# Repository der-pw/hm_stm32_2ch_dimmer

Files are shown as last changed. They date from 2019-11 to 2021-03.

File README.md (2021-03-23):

# hm_stm32_2ch_dimmer

Platinendesign für einen Asksin++ 2 Kanaldimmer, der mit einem STM32 angetrieben wird.
Basiert auf der guten Vorarbeit von pa-pa und seinem STM32 Dimmer https://github.com/pa-pa/STM32Dimmer

top
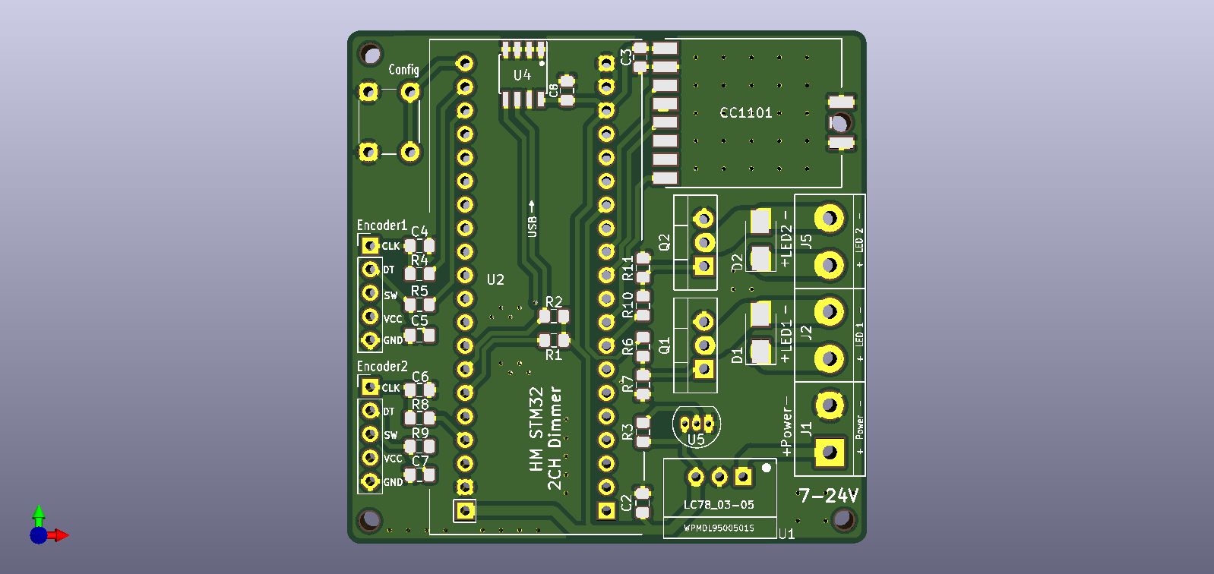
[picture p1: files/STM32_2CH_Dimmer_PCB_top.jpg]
top


bottom
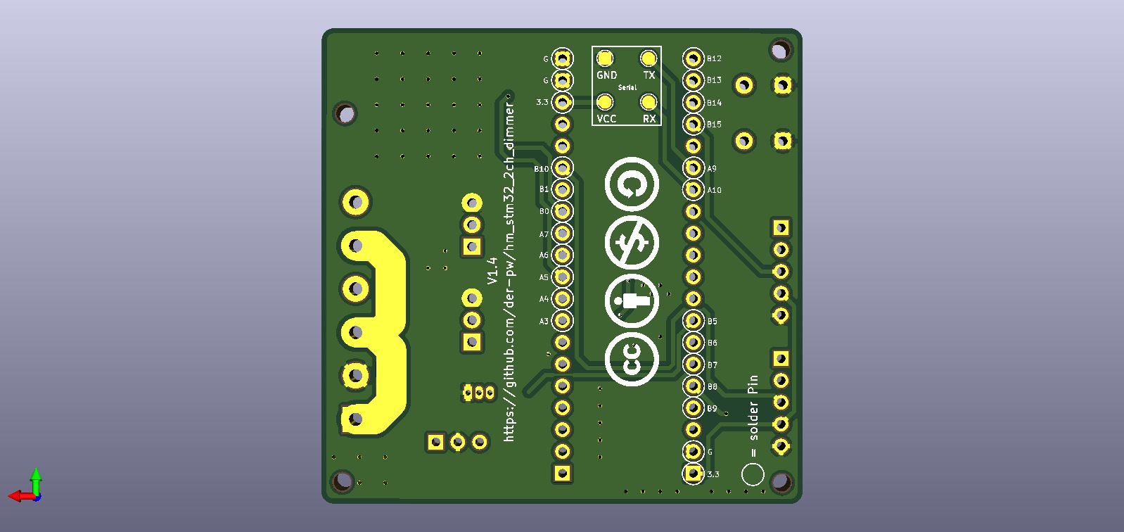
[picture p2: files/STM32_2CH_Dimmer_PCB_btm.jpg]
bottom bottm


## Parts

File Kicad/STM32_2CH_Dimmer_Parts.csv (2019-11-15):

Reference | Quantity | Value | Footprint | Datasheet
C2 | 1 | 22µ | Capacitor_SMD:C_0805_2012Metric_Pad1.15x1.40mm_HandSolder
C3 C8 C7 C6 C5 C4 | 6 | 100n | Capacitor_SMD:C_0805_2012Metric_Pad1.15x1.40mm_HandSolder
D1 D2 | 2 | SS14 | Diodes_SMD:D_SMA | https://de.aliexpress.com/item/100PCS-SMA-Rectifier-diode-1N5819-SS14-1N5822-SS34-SR160-SS16-1N5817-SS12-SR1100-SS110-SR360-SS36/32849859393.html
J1 | 1 | Power | Terminal_Blocks:TerminalBlock_bornier-2_P5.08mm | ~
J2 | 1 | LED1 | Terminal_Blocks:TerminalBlock_bornier-2_P5.08mm | ~
J3 | 1 | Encoder1 | Pin_Headers:Pin_Header_Straight_1x05_Pitch2.54mm | ~
J4 | 1 | Encoder2 | Pin_Headers:Pin_Header_Straight_1x05_Pitch2.54mm | ~
J5 | 1 | LED2 | Terminal_Blocks:TerminalBlock_bornier-2_P5.08mm | ~
Q1 Q2 | 2 | IRF3708 | Package_TO_SOT_THT:TO-220-3_Vertical
R1 R2 R3 | 3 | 4k7 | Resistor_SMD:R_0805_2012Metric_Pad1.15x1.40mm_HandSolder
R6 R10 | 2 | 100R | Resistor_SMD:R_0805_2012Metric_Pad1.15x1.40mm_HandSolder
R7 R11 | 2 | 100k | Resistor_SMD:R_0805_2012Metric_Pad1.15x1.40mm_HandSolder
R8 R9 R4 R5 | 4 | 10k | Resistor_SMD:R_0805_2012Metric_Pad1.15x1.40mm_HandSolder
SW1 | 1 | Config | Button_Switch_THT:SW_PUSH_6mm_H4.3mm | https://de.aliexpress.com/item/100PCS-LOT-3-4-2MM-Micro-button-3X4X2-tact-switch-2-pin-little-turtle-single-shrapnel/32698846968.html
TP1 TP2 TP3 TP4 | 4 | TestPoint | TestPoint:TestPoint_Pad_D1.5mm | ~
U1 | 1 | LC78_03-05 | Homebrew:LC78_03-05 | https://www.reichelt.de/dc-dc-wandler-1-65-w-3-3-v-500-ma-to-220-lc78-03-0-5-p242822.html
U2 | 1 | STM32F103Generic | Homebrew:STM32F103Generic | https://de.aliexpress.com/item/STM32F103CBT6-Maple-Mini-ARM-STM32-Cortex-M3-Controller-Board-Module-3-3V-USB-Digital-IO-PWM/32292673542.html
U3 | 1 | CC1101 | Homebrew:CC1101_Module | https://de.aliexpress.com/item/CC1101-Wireless-Module-Long-Distance-Transmission-Antenna-868MHZ-M115-Free-Shipping/32803645858.html
U4 | 1 | AT24CS32 | Housings_SOIC:SOIC-8_3.9x4.9mm_Pitch1.27mm | https://de.aliexpress.com/item/20PCS-24c32-AT24c32-SOP8-AT24C32AN-10SU-2-7-make-in-china/1517186522.html
U5 | 1 | DS18B20 | TO_SOT_Packages_THT:TO-92_Inline_Narrow_Oval | https://de.aliexpress.com/item/DS18B20-18B20-Programmable-Resolution-1-Wire-Digital-Thermometer-IC-TO-92/32794981963.html

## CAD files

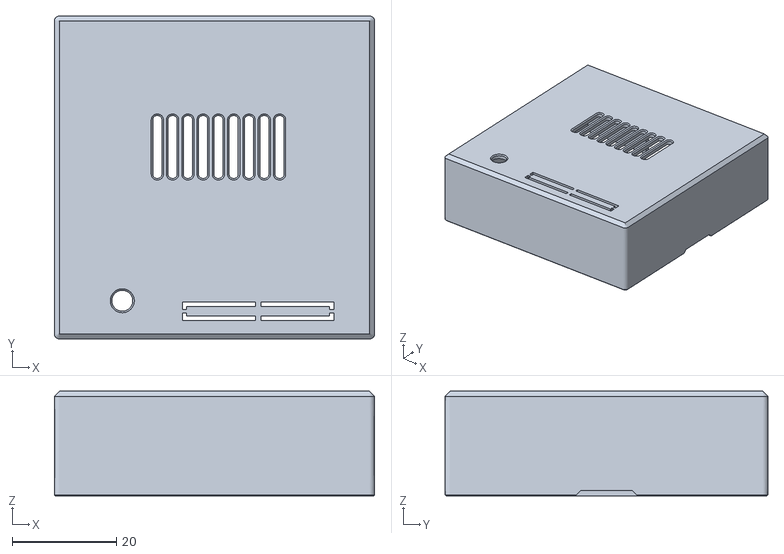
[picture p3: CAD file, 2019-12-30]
Gehaeuse/Deckel.stl
61.4 x 61.9 x 20.1

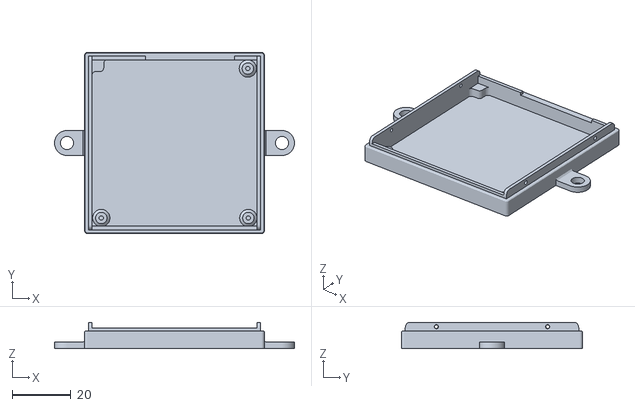
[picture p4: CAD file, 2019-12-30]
Gehaeuse/Grundplatte.stl
81.9 x 61.9 x 9.00

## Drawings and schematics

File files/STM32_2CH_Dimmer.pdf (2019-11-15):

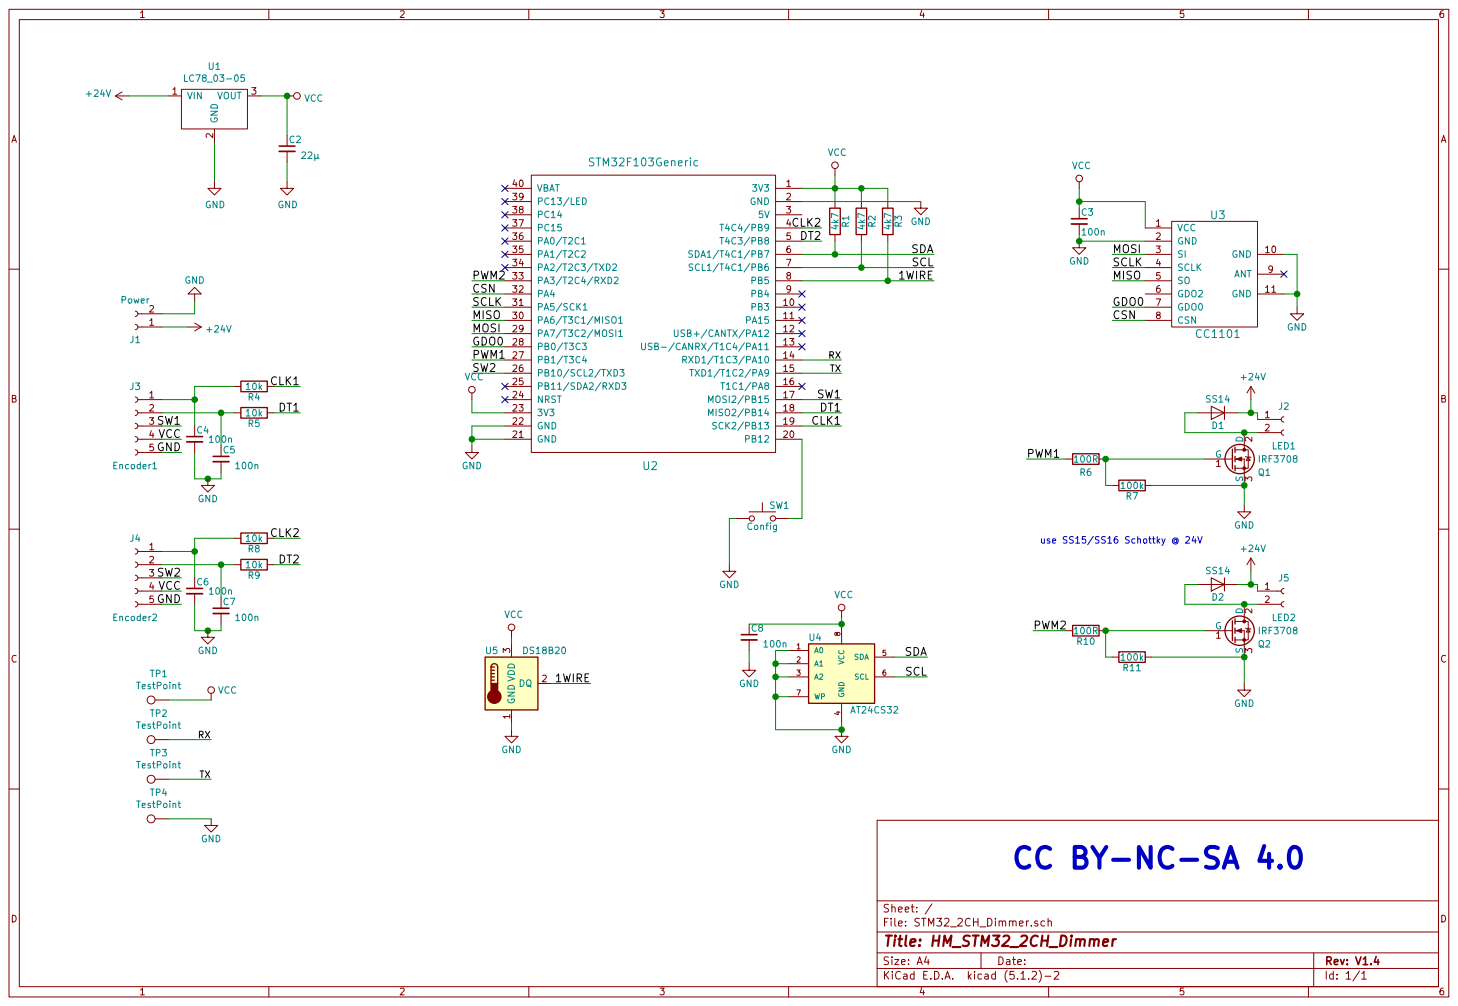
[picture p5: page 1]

4 SDA 5 SCL 6 WP 7 VCC

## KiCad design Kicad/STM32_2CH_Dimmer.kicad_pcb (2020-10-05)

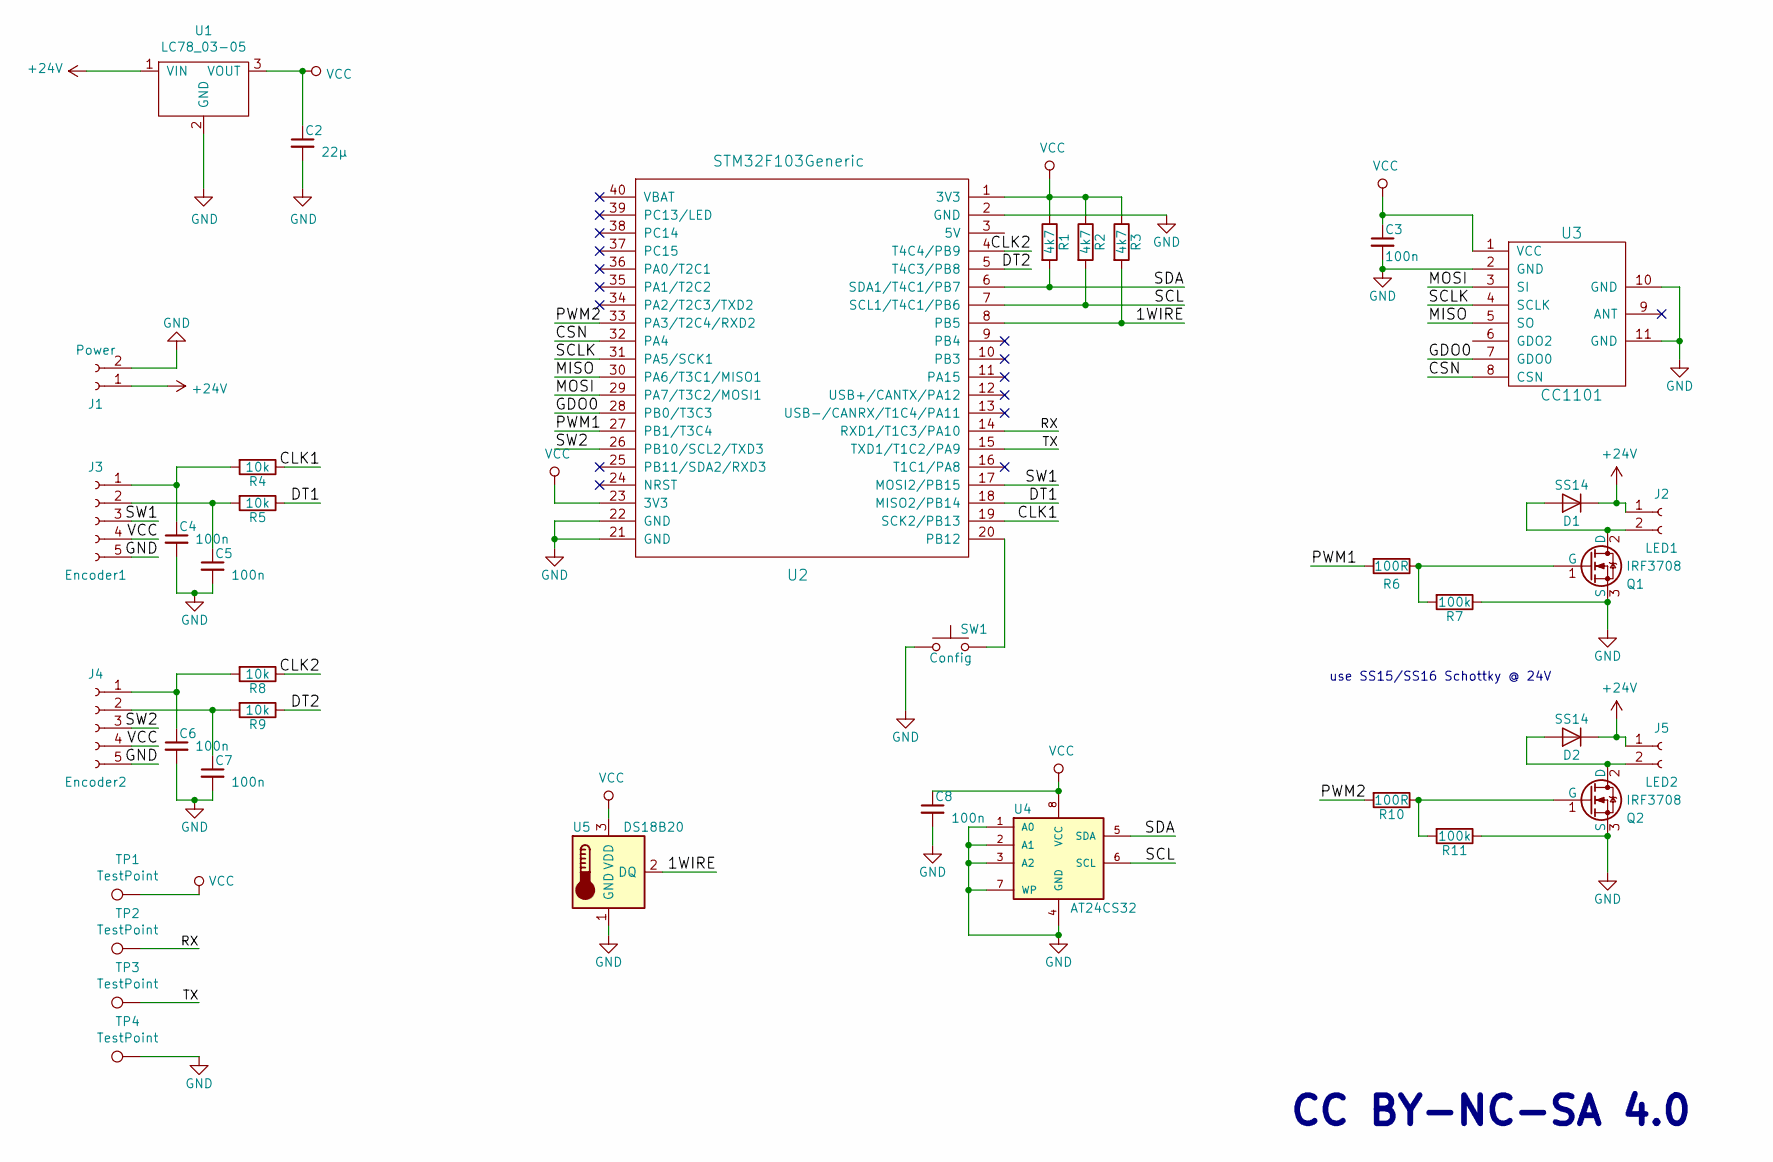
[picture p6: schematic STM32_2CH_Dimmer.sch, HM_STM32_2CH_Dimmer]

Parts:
C2: 22µ; C_0805_2012Metric_Pad1.15x1.40mm_HandSolder
C3, C4, C5, C6, C7, C8: 100n; C_0805_2012Metric_Pad1.15x1.40mm_HandSolder
D1, D2: SS14; D_SMA
J1: Power; TerminalBlock_bornier-2_P5.08mm
J2: LED1; TerminalBlock_bornier-2_P5.08mm
J3: Encoder1; Pin_Header_Straight_1x05_Pitch2.54mm
J4: Encoder2; Pin_Header_Straight_1x05_Pitch2.54mm
J5: LED2; TerminalBlock_bornier-2_P5.08mm
Q1, Q2: IRF3708; TO-220-3_Vertical
R1, R2, R3: 4k7; R_0805_2012Metric_Pad1.15x1.40mm_HandSolder
R4, R5, R8, R9: 10k; R_0805_2012Metric_Pad1.15x1.40mm_HandSolder
R6, R10: 100R; R_0805_2012Metric_Pad1.15x1.40mm_HandSolder
R7, R11: 100k; R_0805_2012Metric_Pad1.15x1.40mm_HandSolder
SW1: Config; SW_PUSH_6mm_H4.3mm
TP1, TP2, TP3, TP4: TestPoint; TestPoint_Pad_D1.5mm
U1: LC78_03-05
U2: STM32F103Generic
U3: CC1101; CC1101_Module
U4: AT24CS32; SOIC-8_3.9x4.9mm_Pitch1.27mm
U5: DS18B20; TO-92_Inline_Narrow_Oval

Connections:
+24V: D1.1 (K), D2.1 (K), J1.1, J2.1, J5.1, U1.1 (VIN)
/1WIRE: R3.2, U2.8 (PB5), U5.2 (DQ)
/CLK1: R4.1, U2.19 (SCK2/PB13)
/CLK2: R8.1, U2.4 (T4C4/PB9)
/CSN: U2.32 (PA4), U3.8 (CSN)
/DT1: R5.1, U2.18 (MISO2/PB14)
/DT2: R9.1, U2.5 (T4C3/PB8)
/GDO0: U2.28 (PB0/T3C3), U3.7 (GDO0)
/MISO: U2.30 (PA6/T3C1/MISO1), U3.5 (SO)
/MOSI: U2.29 (PA7/T3C2/MOSI1), U3.3 (SI)
/PWM1: R6.2, U2.27 (PB1/T3C4)
/PWM2: R10.2, U2.33 (PA3/T2C4/RXD2)
/RX: TP2.1, U2.14 (RXD1/T1C3/PA10)
/SCL: R2.2, U2.7 (SCL1/T4C1/PB6), U4.6 (SCL)
/SCLK: U2.31 (PA5/SCK1), U3.4 (SCLK)
/SDA: R1.2, U2.6 (SDA1/T4C1/PB7), U4.5 (SDA)
/SW1: J3.3, U2.17 (MOSI2/PB15)
/SW2: J4.3, U2.26 (PB10/SCL2/TXD3)
/TX: TP3.1, U2.15 (TXD1/T1C2/PA9)
GND: C2.2, C3.2, C4.2, C5.2, C6.2, C7.2, C8.2, J1.2, J3.5, J4.5, Q1.3 (S), Q2.3 (S), R7.1, R11.1, SW1.1, TP4.1, U1.2 (GND), U2.2 (GND), U2.21 (GND), U2.22 (GND), U3.2 (GND), U3.10 (GND), U3.11 (GND), U4.1 (A0), U4.2 (A1), U4.3 (A2), U4.4 (GND), U4.7 (WP), U5.1 (GND)
unnamed: C4.1, J3.1, R4.2
unnamed: C5.1, J3.2, R5.2
unnamed: C6.1, J4.1, R8.2
unnamed: C7.1, J4.2, R9.2
unnamed: D1.2 (A), J2.2, Q1.2 (D)
unnamed: D2.2 (A), J5.2, Q2.2 (D)
unnamed: Q1.1 (G), R6.1, R7.2
unnamed: Q2.1 (G), R10.1, R11.2
unnamed: SW1.2, U2.20 (PB12)
VCC: C2.1, C3.1, C8.1, J3.4, J4.4, R1.1, R2.1, R3.1, TP1.1, U1.3 (VOUT), U2.1 (3V3), U2.23 (3V3), U3.1 (VCC), U4.8 (VCC), U5.3 (VDD)

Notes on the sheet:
CC BY-NC-SA 4.0
use SS15/SS16 Schottky @ 24V

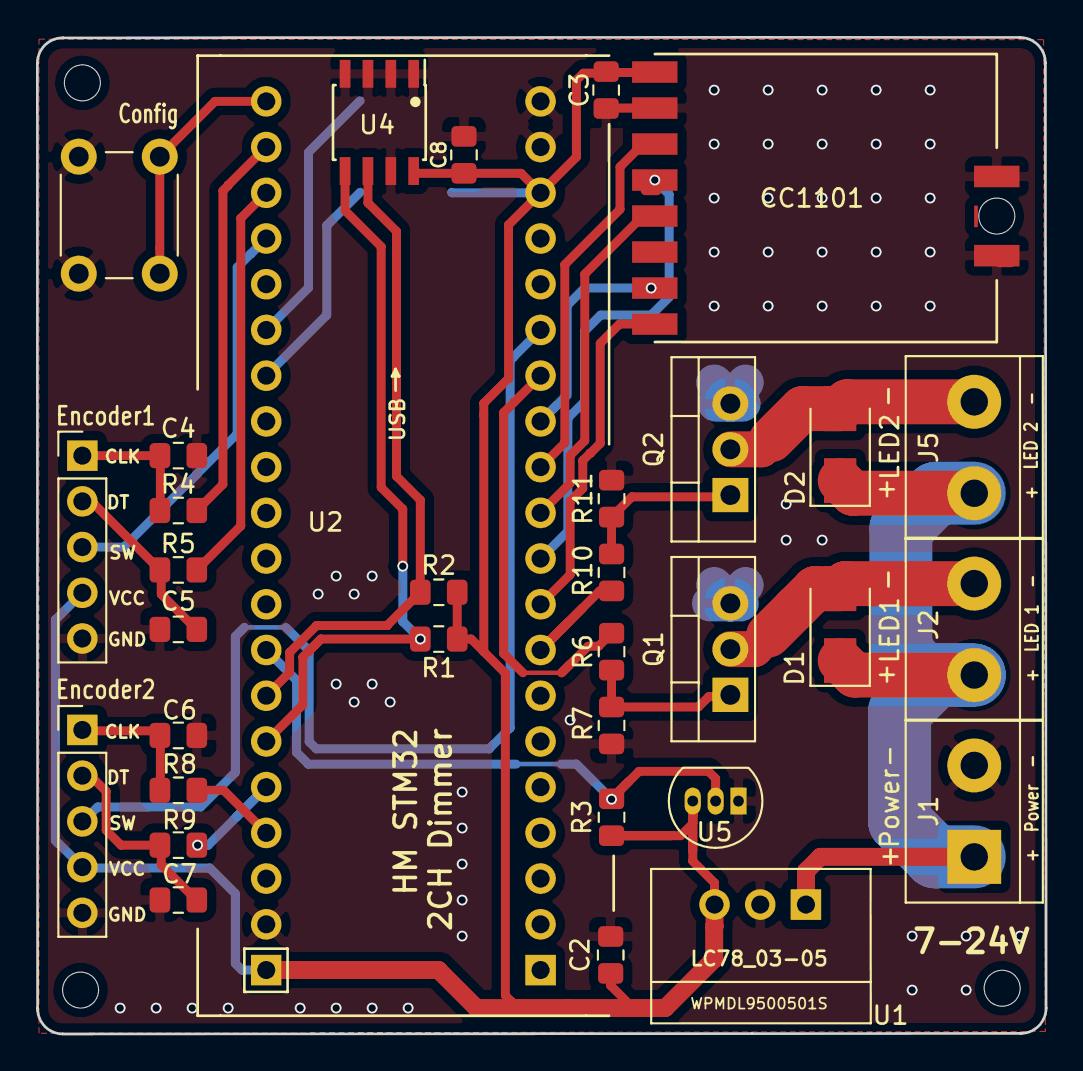
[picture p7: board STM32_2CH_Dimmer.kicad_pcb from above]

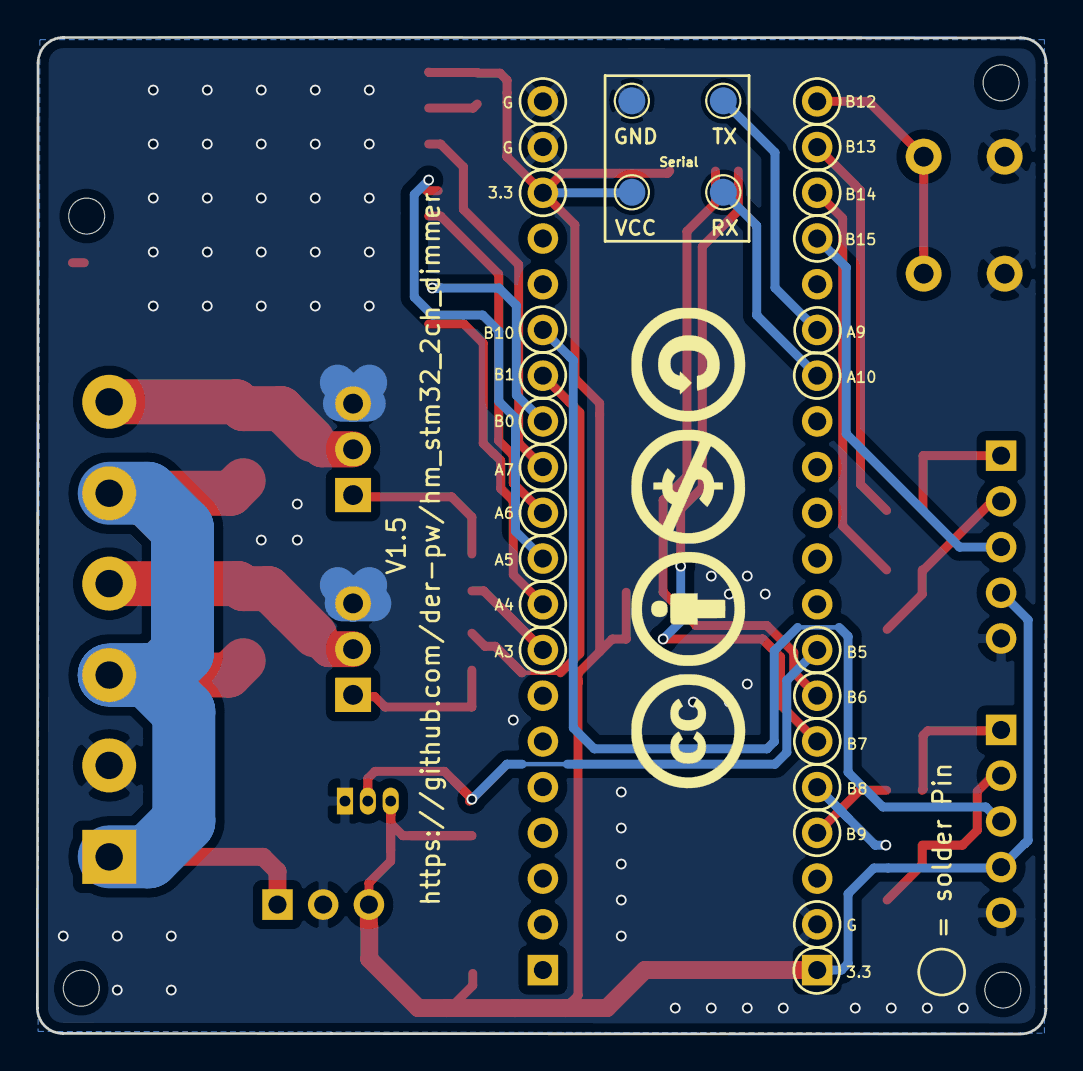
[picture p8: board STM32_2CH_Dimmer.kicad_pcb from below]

Board: 2 copper layers, 56.0 x 55.4 mm, 37 parts (4 on the bottom side), 30 nets.

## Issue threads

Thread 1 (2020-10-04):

Temperatursensor DS18b20 und Platine kaufen oder fertigen lassen?

Triton-KS, 2020-10-04:
Hallo,
ich bin gerade auf der Suche nache einem weiteren LED Dimmer.
Dabei bin ich auf die Seite oder das Projekt aufmerksam geworden.

Wofür wird oder ist der Temperatursensor DS18b20 auf der Platine?

Wo oder wie kann man die Platine kaufen oder darf man die sich "nachbestellen" z.B. bei jlcpcb
und funktioniert das mit den Patinen-Dateien da?

der-pw, 2020-10-05:
Hallo,

der DS18b20 überwacht die Temperatur im Gehäuse, sofern die Platine in
einem Gehäuse verbaut ist.
In der CCU kann eingestellt werden, bei welcher Temperatur um wieviel
Prozent abgedimmt werden soll, wenn es doch mal zu heiß wird, einfach um
Last wegzunehmen.
Ist mir bislang aber noch nicht passiert.

Selbstverständlich kannst du dir die Platinen bei JLC nachbestellen.
Einfach den Ordner "gerber" als Zip-File dort hochladen.
Von der V1.5 hab ich leider keine da.
Eben habe ich das Repo nochmal aufgeräumt, dort findest du jetzt auch eine
gerber.zip. Die kannst du jetzt einfach bei JLC hochladen.

Schöne Grüße,
Patrick

Am So., 4. Okt. 2020 um 22:32 Uhr schrieb Triton-KS <
notifications@github.com>:

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

Triton-KS, 2020-10-05:
Hallo Patrick,

Danke für deine schnelle Rückmeldung.
Mit dem DS18b20 habe ich mir schon sowas gedacht. Kann man den DS18B20 auch als "normalen" Temperatursensor
in / mit der CCU verwenden?

Den Gerber-Ordner als Zip erstellen, ist mir dann auch wieder eingefallen. Hatte bisher nur einmal Platinen bestellt.
So ok dann muss ich nur noch schauen ob der AT24CS32 typengleich mit dem vom Reichelt ist:
[https://www.reichelt.de/eeprom-32-kb-4096-x-8-25-5-5-v-so-8-st-24c32-mn6-p33376.html?&trstct=pos_0&nbc=1](url)
benötigt man hier ggf 64 kB oder bring ein Wechsel eher Probleme ?

Letzte Frage gibt es Unterschiede zwischen STM32F103C**B**T6 und STM32F103C**8**T6 oder wenn man den STM32F103C**B**T6 nicht bekommt gibt es eine Alternative?

Schöne Grüße

Triton-KS / Alex

Closed 2020-10-14.

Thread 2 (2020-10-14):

STM32F103 Bild und Bestelllink unterschiedlich

Triton-KS, 2020-10-14:
Hallo,
ich bin noch etwas verunsichert über den STM32F103
Es scheint ja ein Maple Mini zu sein oder ist es ein Blue Pill?
Leider ist der STM32F103 über den Bestelllink optisch ein völlig anderer
Artikel. Gibt es hier Hilfestellungen auf was man achten muss?

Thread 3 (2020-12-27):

Memory/EEPROM 64kB oder nur 32kB

Triton-KS, 2020-12-27:
Hi,
ist es auch möglich einen EEPROM mit 64kB zu benutzen?
Auf was sollte man hierbei achten?

Danke

der-pw, 2020-12-28:
Hallo,
kann ich gar nicht genau beantworten.
Wobei 64kB wohl etwas groß sein dürfte, ob aber auch 64k**b** gehen weiß ich nicht. ;-)

Wenn es dir aber nur darum geht, dass der AT24C**S**32 schlecht verfügbar ist, der AT24C32 geht auch.
https://homematic-forum.de/forum/viewtopic.php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

Triton-KS, 2020-12-28:
Hallo,
Dankeschön.
Genau den im Forum beschriebenen oder als Link bei Reichelt benannten habe ich bestellt.
Leider muss ich hier nochmal genauer schauen oder herausfinden wo der Pin 1 ist. Es fehlen auf den bestellten EEPROMs der Markierungspunkt. Aber sollte man ja herausfinden.
Gestatten Sie oder du mir noch die Frage was die Aufgabe vom EEPROM genau ist? Einfach nur um es zu verstehen.
Danke

der-pw, 2020-12-28:
"du" ist vollkommen in Ordnung.

Im EEPROM werden die Deviceparamter und Peerings gespeichert.
Quasi das was du in der CCU für das jeweilige Gerät konfigurieren kannst.
(achtung gefährliches Halbwissen) Der STM32 besitzt kein internes EEPROM wie bspw. der AT328P, sondern nur Flashspeicher, welcher IMHO weniger Schreibzyklen als eben ein EEPROM verträgt.

Ja, die sind ja witzig bei ST. :-D
Hab mir meine, bei Reichelt bestellten noch nie angeguckt, da ich noch von ein paar AT-Chips zehre, und so oft baue ich den Dimmer jetzt nicht zusammen.

Wenn sich die Ausrichtung des Aufdrucks analog zum Atmel-EEPROM verhält, sollte Pin1 unten links sein.
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

Triton-KS, 2020-12-29:
Servus,
scheinbar lernt man noch mehr durch das Bauen.
ST machen die Kennzeichnung wohl über die Form.
Erkennt man ja auh gut über die Vergrößerung

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

der-pw, 2020-12-29:
Ah, sehr gut!
Haben wir wieder was gelernt.

Danke für die Info.

Closed 2020-12-29.

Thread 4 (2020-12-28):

Encoder1/2 Funktion?

Triton-KS, 2020-12-28:
Hallo,
die Encoder 1 und Encoder 2 dienen zur externen "Ansteuerung / Helligkeitsveränderung" der angeschlossenen LEDs,
ist das richtig?
Und wenn ja wie steuert man diese dann genau an oder gibt es dafür auch einen Schaltung oder Platine?

der-pw, 2020-12-28:
Im Prinzip brauchst du nichts weiter als einen Drehencoder.
https://www.amazon.de/RoboMall-Drehencoder-Drehgeber-KY-040-Modul/dp/B00QHEMUQK

Den verbindest du gemäß der Pinbezeichnung auf der Platine, und das Hühnerfutter natürlich nicht vergessen.
In den meisten Sketches sollte das dank pa-pa auch eingebaut sein.
https://github.com/pa-pa/AskSinPP/blob/master/examples/stm32/HM-LC-DW-WM/HM-LC-DW-WM.ino#L74-L75

Triton-KS, 2020-12-28:
Ohje danke,
was man nicht alles nach ca. 20 Jahren Lehre an Begriffen vergisst oder einfach zu kompliziert Denkt.
Keine Ahnung was ist hier für eine "wilde" Schaltung erwartet hatte. Aber naja wenn man erst wieder anfängt zu "Basteln" oder sind nebenbei mit Platinen zu beschäftigen, hat man halt noch Wissenslücken.

Dankeschön

Closed 2020-12-29.

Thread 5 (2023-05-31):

Teileliste down

DennisXK, 2023-05-31:
Hi kannst du die Teileliste neu hochladen, denn die ist down!

der-pw, 2023-06-01:
https://github.com/der-pw/hm_stm32_2ch_dimmer/blob/master/Kicad/STM32_2CH_Dimmer_Parts.csv
was ist denn mit dieser Liste hier?

DennisXK, 2023-06-01:
Ok danke. Hätte noch ein paar Fragen...

-kann man für den EPROM auch einen anderen benutzen? Denn den gibt es beim Conrad, RS, Reichelt nicht. Hättest du du ein alternative EMPROM?

-Der DS18B20 wird der auch ausgelesen und von der Homematic Oberfläche angezeigt? Wäre cool wenn das so wäre :D

-J2 und J3: benötigt man für was genau? Denke nicht das die für den Dimmer nötwenig sind

-U2 welchen Controller genau? STM32 F103C6T6 oder STM32 F103C8T6?

Closed 2023-06-12.

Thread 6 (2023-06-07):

Fragen

DennisXK, 2023-06-07:
Habe leider keine Antwort erhalten, deswegen eine neues Issues.

-kann man für den EPROM auch einen anderen benutzen? Denn den gibt es beim Conrad, RS, Reichelt nicht. Hättest du du ein alternative EMPROM?

-Der DS18B20 wird der auch ausgelesen und von der Homematic Oberfläche angezeigt? Wäre cool wenn das so wäre :D

-J2 und J3: benötigt man für was genau? Denke nicht das die für den Dimmer nötwenig sind

-U2 welchen Controller genau? STM32 F103C6T6 oder STM32 F103C8T6?

der-pw, 2023-06-10:
> kann man für den EPROM auch einen anderen benutzen? Denn den gibt es beim Conrad, RS, Reichelt nicht. Hättest du du ein alternative EMPROM?

diesen von ST solltest du nehmen können
https://www.reichelt.de/eeprom-32-kb-4k-x-8-i2c-400-khz-2-5--5-5-v-so-8-st-24c32-mn6-p33376.html

> -Der DS18B20 wird der auch ausgelesen und von der Homematic Oberfläche angezeigt?

nein, er ist nur für die interne Schutzabschaltung

> -J2 und J3: benötigt man für was genau? Denke nicht das die für den Dimmer nötwenig sind

J2 ist der Terminalanschluss für LED1, musst du wissen, wie du deine LED-Strip da verbindest
und J3 der Pinheader um einen Encoder anzuschließen.
Schätze mal, du meist J3 und J4. Die müssen nicht zwingend verwendet werden.

> U2 welchen Controller genau? STM32 F103C6T6 oder STM32 F103C8T6?

Der Blue Pill hat einen STM32F103C8T6 drauf

Closed 2023-06-12.

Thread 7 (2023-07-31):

endcoder ohne Funktion

DennisXK, 2023-07-31:
Hi, ich habe den HM-LC-Dim1PWM-CV aufgespielt. aber leider ist der Drehendcoder ohne funktion. Muss im Sketch noch etwas aktviert werden?

Diese habe ich verwendet. Habe zum Test auch einen zweiten getestet.

https://www.amazon.de/GIAK-Drehwinkelgeber-Druckknopf-Automobilelektronik-Multimedia-Audio/dp/B09726Y8RB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

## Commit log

2019-09-29 some fixes
    [STM32_2CH_Dimmer.kicad_pcb]
2019-11-04 Gerber export
    [STM32_2CH_Dimmer-B_Cu.gbl, STM32_2CH_Dimmer-B_Mask.gbs, STM32_2CH_Dimmer-B_Paste.gbp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]
2019-11-04 part csv
    [STM32_2CH_Dimmer_Parts.csv]
2019-11-08 V1.3
    minor fixes
    add test pads for serial connection
    [STM32_2CH_Dimmer-B_Cu.gbl, STM32_2CH_Dimmer-B_Mask.gbs, STM32_2CH_Dimmer-B_Paste.gbp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]
2019-11-09 info C1
    [STM32_2CH_Dimmer.sch, STM32_2CH_Dimmer_Parts.csv]
2019-11-15 update 1.4 final
    [STM32_2CH_Dimmer-B_Cu.gbl, STM32_2CH_Dimmer-B_Mask.gbs, STM32_2CH_Dimmer-B_Paste.gbp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]
2019-12-28 Update V1.5
    add missing Via at R3
    [STM32_2CH_Dimmer-B_Cu.gbl, STM32_2CH_Dimmer-B_Mask.gbs, STM32_2CH_Dimmer-B_Paste.gbp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]
2019-12-30 Gehäuse
    [Deckel.stl, Grundplatte.stl]
2020-10-05 cleanup und create gerber.zip
    [STM32_2CH_Dimmer.kicad_pcb, STM32_2CH_Dimmer.sch, STM32_2CH_Dimmer_Parts.csv]
